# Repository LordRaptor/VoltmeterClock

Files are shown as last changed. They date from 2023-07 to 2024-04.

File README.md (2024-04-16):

# Voltmeter Clock v2.0

## Controls

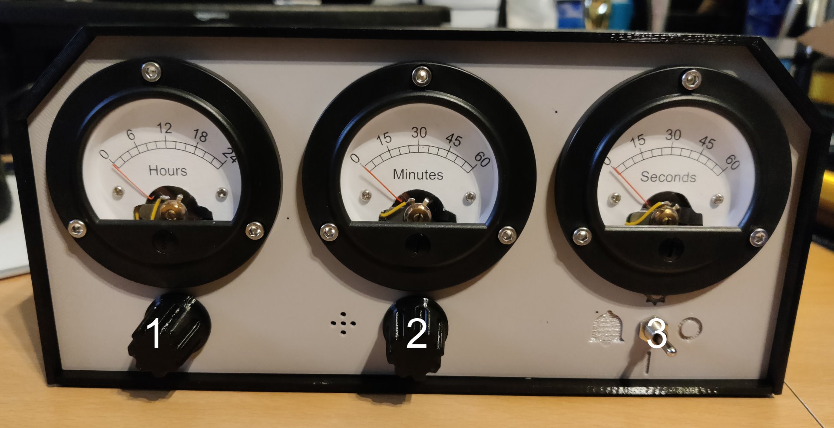
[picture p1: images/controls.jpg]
Controls


* Knob 1: Rotate to change backlight brightness. Press and hold for 1-2s to enter time setting mode
* Knob 2: Click to change time display mode
* Switch 3: Controls alarm

## Startup
When the clock is connected to power, a startup routine will run, slowly pulsing the backlights and moving all indicators to their maximum position and back, before continuing to normal operation. If the timekeeping was lost, the clock will instead switch to time setting mode.

Use this to confirm that all indicators move freely.

## Backlight
There is a yellow LED backlight installed in each display. Use __Knob 1__ to increase or decrease brightness.  Rotate clockwise to increase and counter-clockwise to decrease backlight brightness. This setting persists, even if power is lost

## Time display mode

The clock supports two modes to display time, _digital_ and _analog_. Press __Knob 2__ to switch between these. This setting persists, even if power is lost.

* _Digital display mode_: Indicators will point to the current hour, minute and second and move in discrete steps as time moves on. So the seconds indicator will move once per seconds, the minute indicator once per minute and the hours indicator once per hour.
* _Analog display mode_: Indicators will move smoothly as time progresses.

## Time setting mode
Press and hold __Knob 1__ until the backlight LEDs start blinking (1-2 seconds). The clock will always switch to _digital display mode_ to make setting the time easier. Rotate __Knob 1__ to set the hour, and __Knob 2__ to set the minute. Press __Knob 1__ again (a short click will be enough) to exit time setting mode. Seconds will always be reset to 0 and start counting again when the new time is confirmed.

## Alarm

__Switch 3__ has three positions:

* __Up:__ Set alarm time
* __Middle:__ Alarm disabled
* __Down:__ Alarm armed

To set the alarm, move the __Switch 3__ to the __up__ position. Use __Knob 1__ and __Knob 2__ to set the hour and minute of the alarm time. Note that the minutes can only be set in 5 min intervals.

While setting the alarm time, press __Knob 2__ to change the alarm melody. 6 different melodies are available

1. Star Wars
1. Game of Thrones
1. Harry Potter
1. Pirates of the Caribbean
1. Tetris
1. Mario

To save the alarm time, move __Switch 3__ to the __middle__ or __down__ position.

Alarm time and selected melody is persisted, even if power is lost.

## Calibration Mode
Not used in normal operation.

Pressing __Knob 2__ for 1-2 seconds will enter calibration mode, backlight LEDs  will start pulsing slowly. This mode is used to calibrate the displays,
adjusting the display potentiometers on the circuit board until the indicators points to the end of the dial scale. __Knob 1__ will move the hour dial, __Knob 2__ will move the minutes and seconds dials.

Long pressing __Knob 1__ again for 1-2 seconds will exit this mode and normal operation will resume.

## Backup power
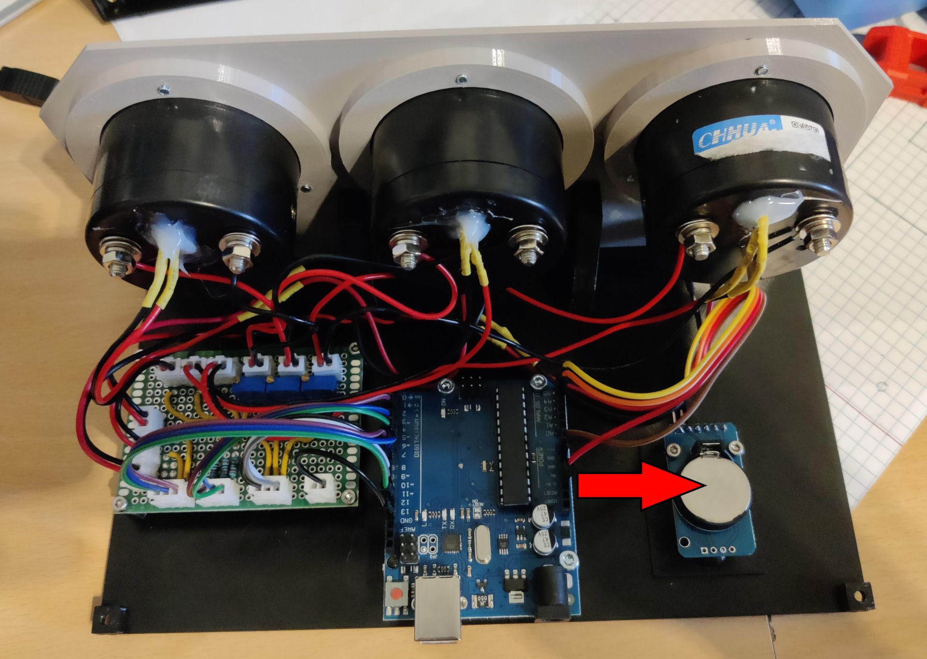
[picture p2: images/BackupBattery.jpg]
Coin cell battery location


The clock includes a slot for a CR2032 3V coin cell battery to ensure time keeping even if main power is lost. To replace the battery, open the clock by removing the four (4) screws at the bottom of the clock and lifting off the outer case. Insert the coin cell battery into the holder located on the small module in the clock (see picture).

## Power Supply
Ideally the clock is powered using a 5.5 X 2.1 jack with a 7-12V power supply, with ~7V being recommended.

Powering the clock via the USB B port (which only provides 5V) will also work, but
the display will not be accurate as the backlight brightness will affect the indicators in this case.

## Serial output
Connecting a USB B cable to the clock, a serial monitor using a baud rate of 115200 will allow you to read the debug output of the clock.

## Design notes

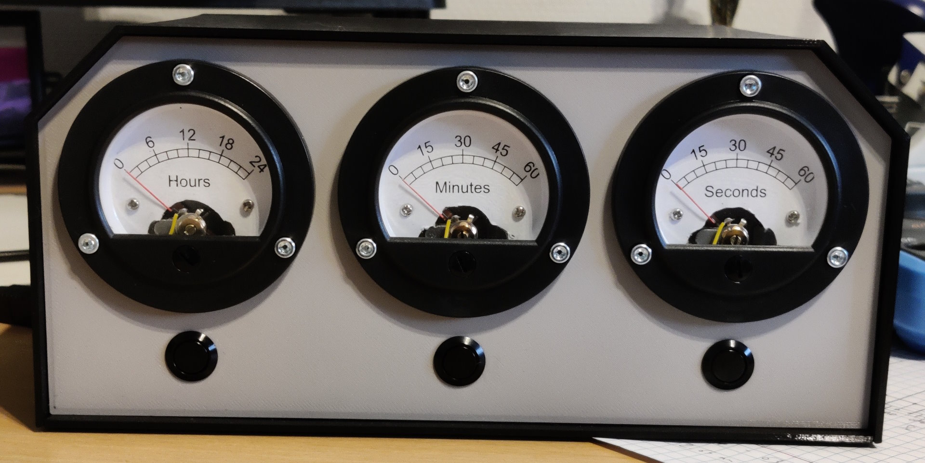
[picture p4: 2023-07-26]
images/Front.jpg

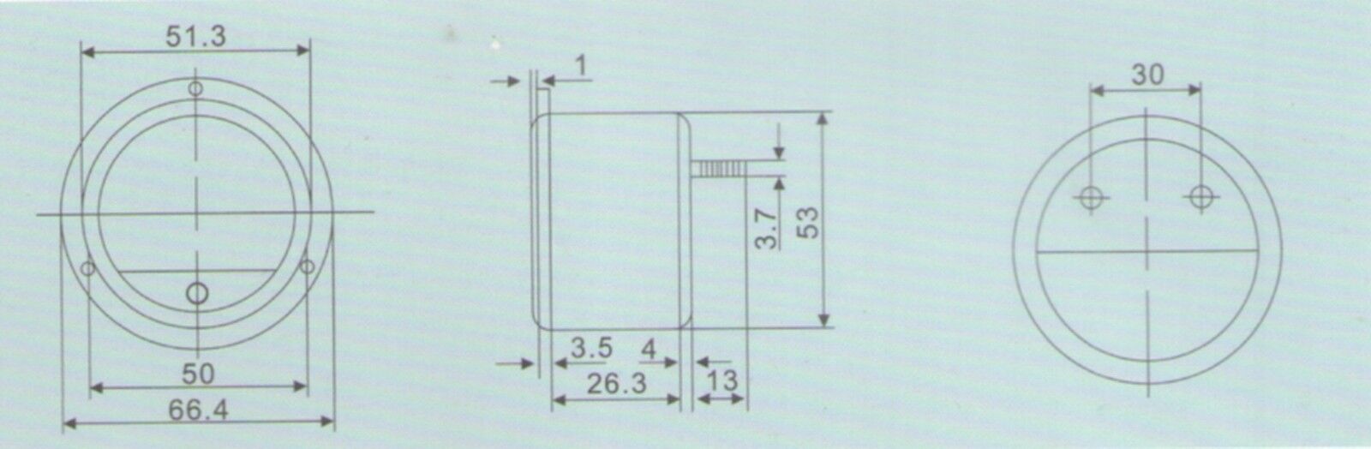
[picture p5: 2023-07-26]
assets/3D Models/DH-52 Dimensions.jpg

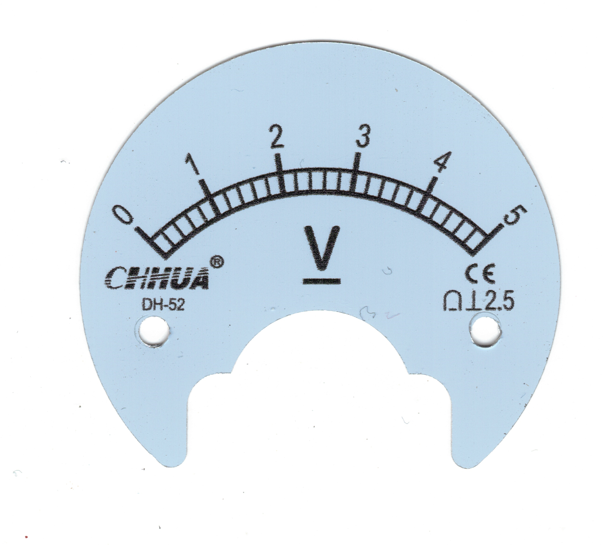
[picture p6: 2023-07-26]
assets/Dials/DH-52 Dial.png

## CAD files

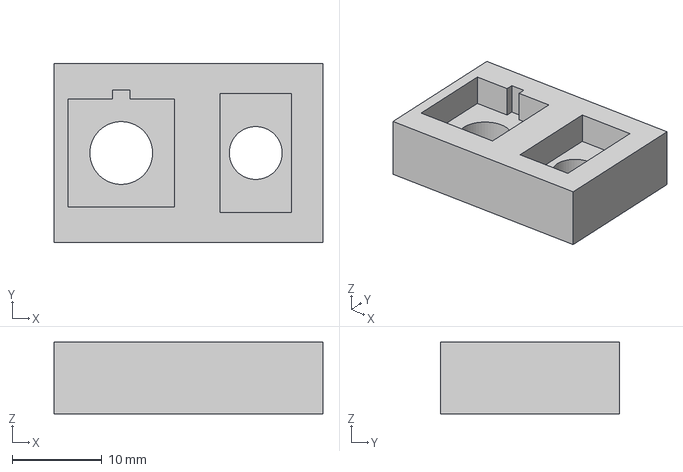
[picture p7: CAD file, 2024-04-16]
assets/3D Models/Encoder and Switch Fitting Test v1.3mf
30.0 x 20.0 x 8.00 mm

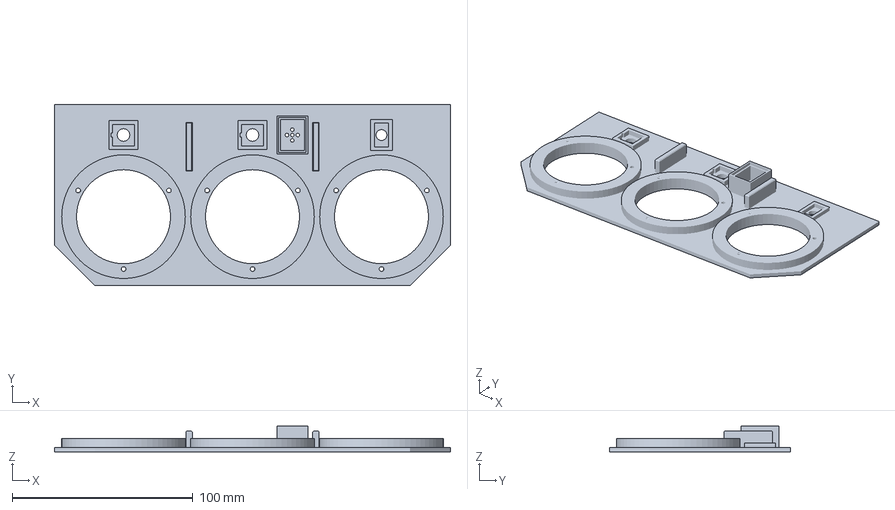
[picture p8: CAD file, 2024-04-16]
assets/3D Models/Version 2/Front 2.0.3mf
219.2 x 100.4 x 14.3 mm

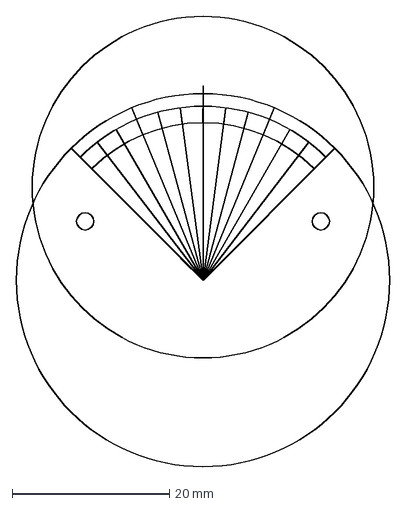
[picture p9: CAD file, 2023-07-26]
assets/Dials/Dial Scale.dxf
47.5 x 57.3 mm

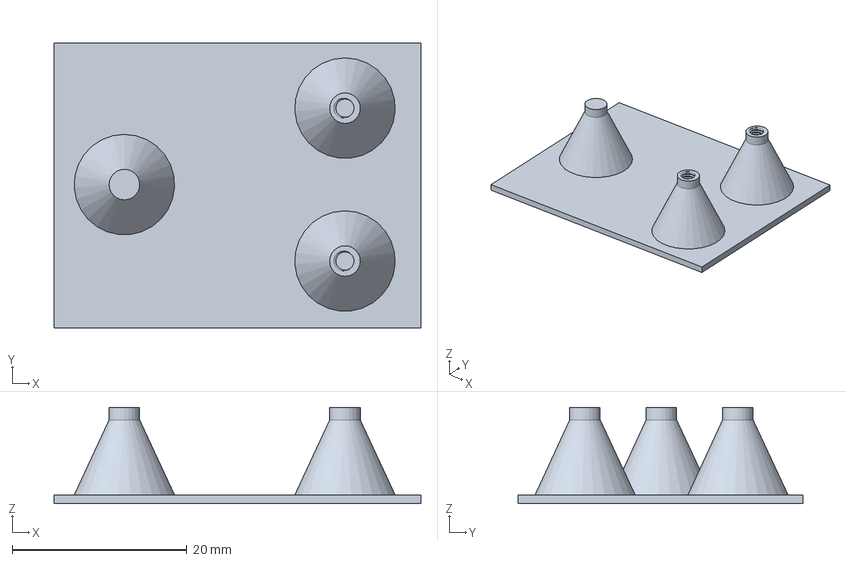
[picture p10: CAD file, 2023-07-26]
assets/3D Models/RTC Holder.3mf
42.0 x 32.7 x 11.0 mm

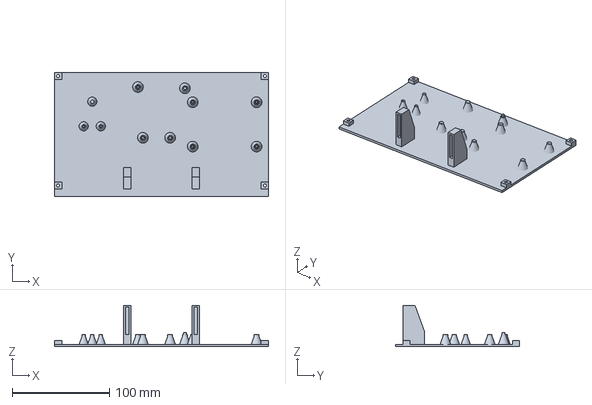
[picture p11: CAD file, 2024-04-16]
assets/3D Models/Version 2/Bottom 2.0.3mf
219.6 x 127.4 x 42.5 mm

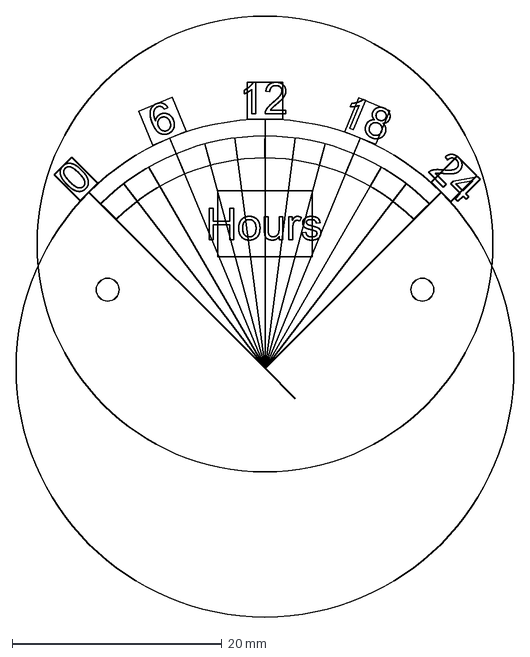
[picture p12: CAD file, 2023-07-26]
assets/Dials/Hours Dial.dxf
47.5 x 57.3 mm

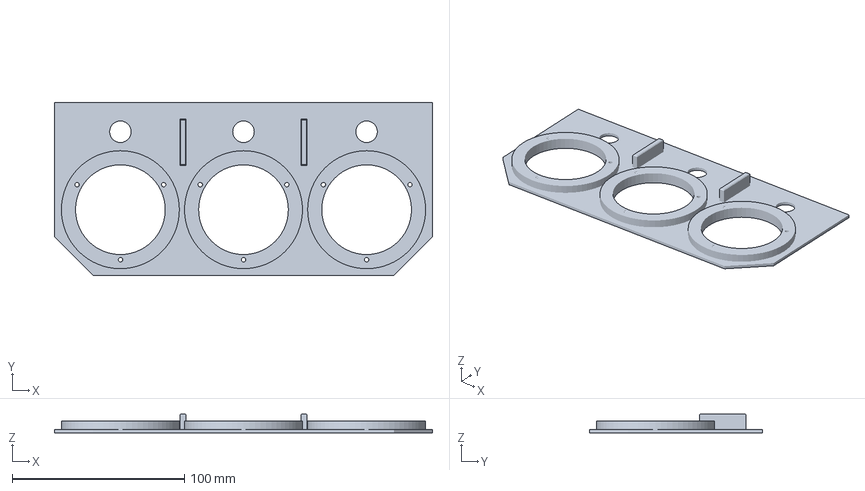
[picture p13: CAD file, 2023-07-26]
assets/3D Models/Frontpanel.3mf
219.2 x 100.4 x 11.0 mm

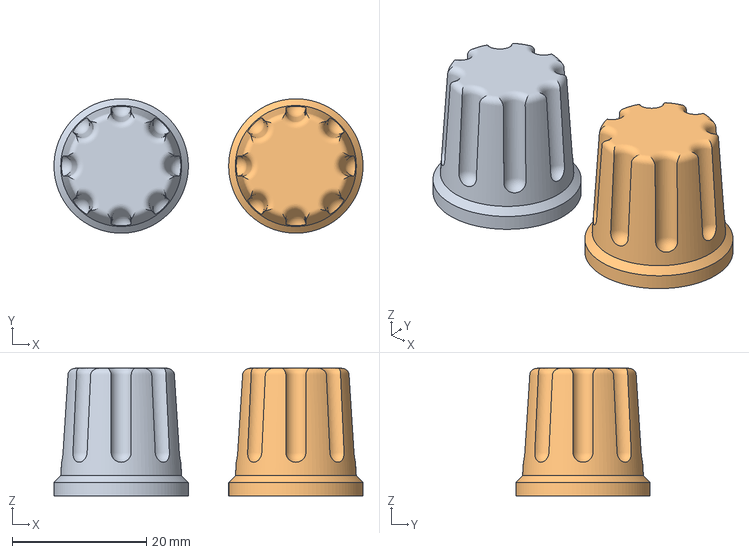
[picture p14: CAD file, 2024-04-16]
assets/3D Models/Version 2/Kob v9.3mf
46.0 x 20.0 x 19.0 mm

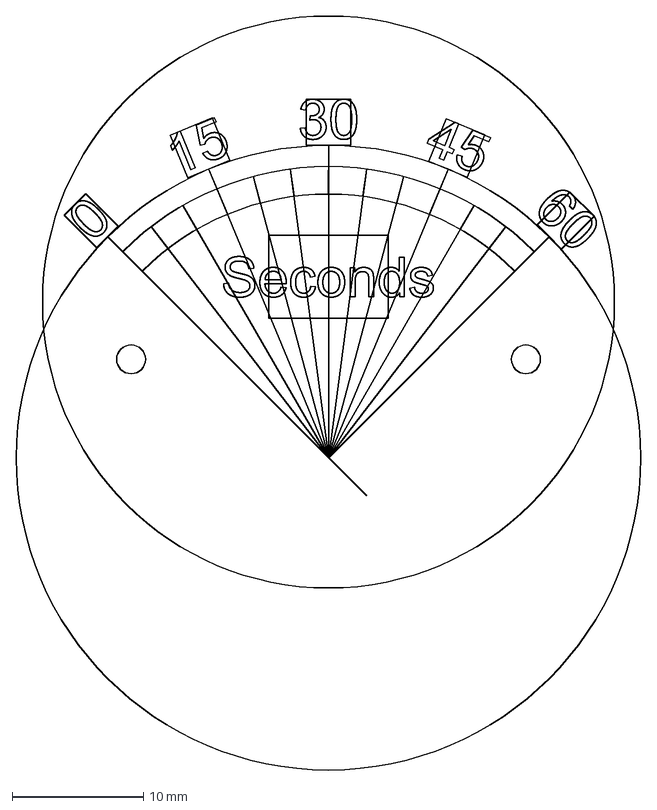
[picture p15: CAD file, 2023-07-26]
assets/Dials/Seconds Dial.dxf
47.5 x 57.3 mm

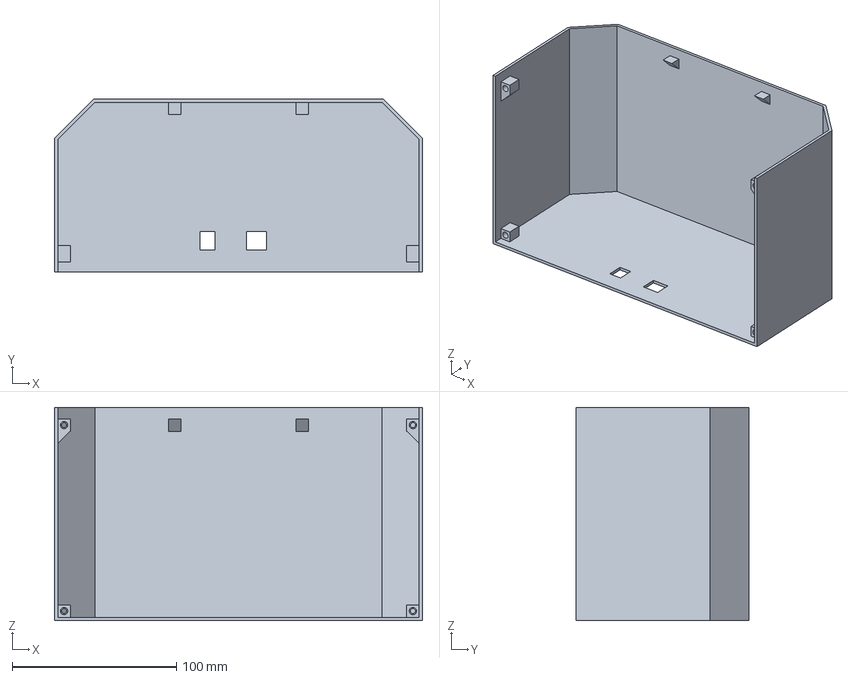
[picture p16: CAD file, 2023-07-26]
assets/3D Models/Case.3mf
224.2 x 105.4 x 130.0 mm

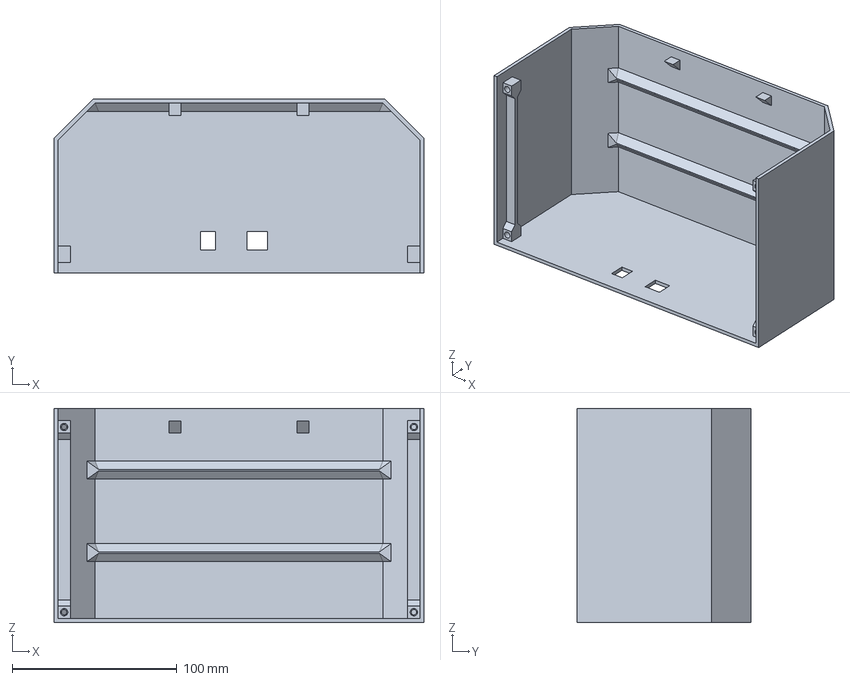
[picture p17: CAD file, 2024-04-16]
assets/3D Models/Version 2/Case 2.0.3mf
224.4 x 105.6 x 130.0 mm

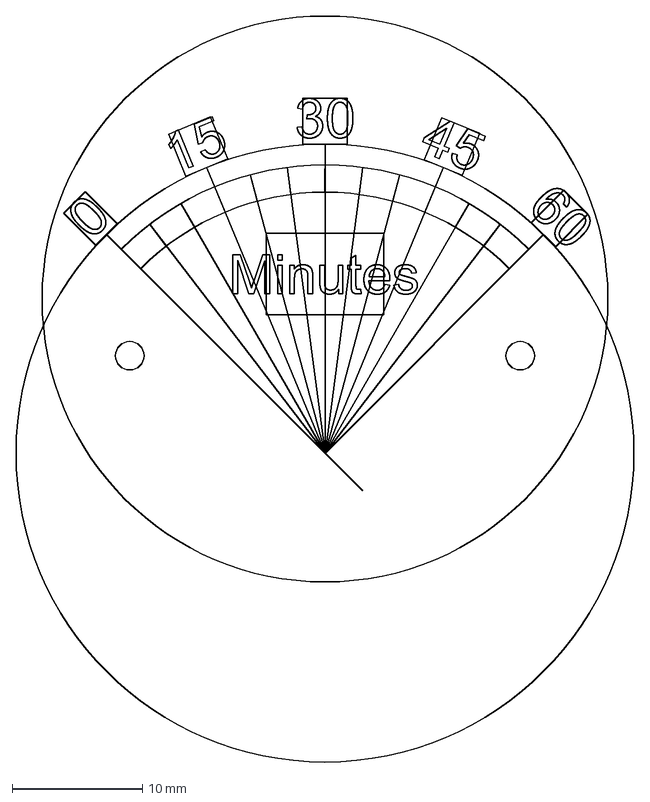
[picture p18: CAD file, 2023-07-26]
assets/Dials/Minutes Dial.dxf
47.5 x 57.3 mm

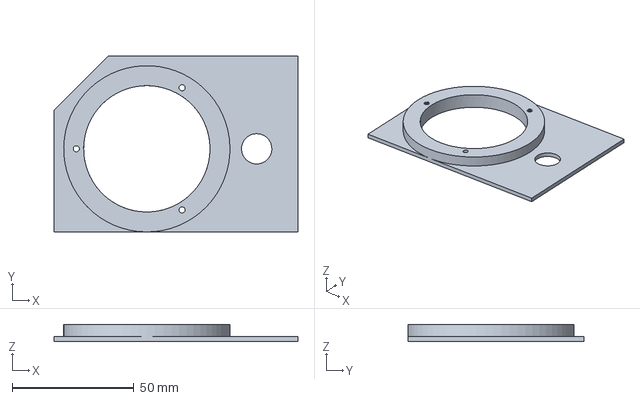
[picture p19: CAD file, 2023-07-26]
assets/3D Models/FrontPanel Fit Test.3mf
100.4 x 72.4 x 7.00 mm

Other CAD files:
assets/3D Models/Bottom Panel.3mf
assets/3D Models/Version 2/Front 2.0 v13.3mf

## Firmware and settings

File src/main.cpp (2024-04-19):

#define VERBOSE_DEBUG

#include <Arduino.h>
#include <voltmeter/VoltmeterManager.h>
#include <led/SmoothLedManager.h>
#include <RTClib.h>
#include <avdweb_Switch.h>
#include <Encoder.h>
#include <alarm/ToneAlarm.h>


// Voltmeters
// Do not use Pins 5 and 6 for Voltmeters
#define HOURS_VOLTMETER_PIN 10
#define MINUTES_VOLTMETER_PIN 9
#define SECONDS_VOLTMETER_PIN 6
#define VOLTMETER_STEPS_PER_SECOND 255

// LEDs
#define LED_PIN 5

// Buzzer
#define BUZZER_PIN 11

// Rotary Encoders
#define HOURS_ENCODER_CLK 2
#define HOURS_ENCODER_DT 3
#define HOURS_ENCODER_SWITCH 14
#define MINUTES_ENCODER_CLK 17
#define MINUTES_ENCODER_DT 16
#define MINUTES_ENCODER_SWITCH 15

// Front switch
#define FRONT_SWITCH_UP 7
#define FRONT_SWITCH_DOWN 8

// Alarm
#define ALARM_LOOP_COUNT 3

// put function declarations here:
void startupRoutine();
void displayTimeLoop();

void writeTimetoSerial(uint8_t hours, uint8_t minutes, uint8_t seconds);

void enterSettings();
void settingStateLoop();
void exitSettings();

void enterCalibration();
void calibrationStateLoop();
void exitCalibration();

void enterAlarmSet();
void alarmSetLoop();
void exitAlarmSet();

void buttonSingleClickedCallback(void *ref);
void buttonLongPressedCallback(void *ref);
void buttonPushedCallback(void *ref);

void readEncoders();

const byte HOUR_SWITCH_ID = 1;
const byte MINUTES_SWITCH_ID = 2;
const byte FRONT_SWITCH_UP_ID = 3;
const byte FRONT_SWITCH_DOWN_ID = 4;

enum ClockState
{
  startup,
  displayTime,
  setting,
  calibration,
  setAlarm
};
ClockState state = startup;

struct TimeData
{
  uint8_t hours = 0;
  uint8_t minutes = 0;
  uint8_t seconds = 0;
};
TimeData rtcTimeHolder = {};

struct DisplayTimeStateData
{
  unsigned long lastRTCPoll = 0;
  unsigned long lastSecondChange = 0;
  unsigned long lastSerialOutput = 0;

  unsigned long rtcUpdateInterval = 50;
  unsigned long serialOutputInterval = 10000;
};
DisplayTimeStateData displayStateData = {};

SmoothLedManager ledManager(LED_PIN);

VoltmeterManager voltmeterManager(
    VoltmeterConfig{
        HOURS_VOLTMETER_PIN,
        MINUTES_VOLTMETER_PIN,
        SECONDS_VOLTMETER_PIN,
        VOLTMETER_STEPS_PER_SECOND});

Switch hourButton = Switch(HOURS_ENCODER_SWITCH, INPUT_PULLUP, LOW, 50, 2000, 250, 10);
Switch minutesButton = Switch(MINUTES_ENCODER_SWITCH, INPUT_PULLUP, LOW, 50, 2000, 250, 10);

Switch alarmSetButton = Switch(FRONT_SWITCH_UP, INPUT_PULLUP, LOW, 50, 1000, 250, 10);

Encoder hourEncoder = Encoder(HOURS_ENCODER_CLK, HOURS_ENCODER_DT);
Encoder minutesEncoder = Encoder(MINUTES_ENCODER_CLK, MINUTES_ENCODER_DT);

struct EncoderData
{
  long encoderPos = 0;
  long newEncoderPos = 0;
  bool encoderUp = false;
  bool encoderDown = false;
};

EncoderData hourEncoderData = {};
EncoderData minutesEncoderData = {};

RTC_DS3231 rtc;

ToneAlarm toneAlarm = ToneAlarm(BUZZER_PIN);

void setup()
{
  pinMode(BUZZER_PIN, OUTPUT);
  noTone(BUZZER_PIN);

  Serial.begin(115200);

  if (!rtc.begin())
  {
    Serial.println(F("Couldn't find RTC"));
    Serial.flush();
    while (true)
      ;
    // TODO: Enter an error state
  }
  Serial.println(F("Found RTC"));

  rtc.disable32K();
  rtc.clearAlarm(1);
  rtc.clearAlarm(2);
  rtc.disableAlarm(2);

  hourButton.setSingleClickCallback(&buttonSingleClickedCallback, (void *)&HOUR_SWITCH_ID);
  minutesButton.setSingleClickCallback(&buttonSingleClickedCallback, (void *)&MINUTES_SWITCH_ID);

  hourButton.setLongPressCallback(&buttonLongPressedCallback, (void *)&HOUR_SWITCH_ID);
  minutesButton.setLongPressCallback(&buttonLongPressedCallback, (void *)&MINUTES_SWITCH_ID);

  alarmSetButton.setPushedCallback(&buttonPushedCallback, (void *)&FRONT_SWITCH_UP_ID);

  pinMode(FRONT_SWITCH_DOWN, INPUT_PULLUP);

  ledManager.begin();

  voltmeterManager.begin();

  toneAlarm.begin();

  state = startup;
}

void loop()
{
  readEncoders();
  hourButton.poll();
  minutesButton.poll();
  alarmSetButton.poll();

  switch (state)
  {
  case startup:
    startupRoutine();
    break;
  case displayTime:
    displayTimeLoop();
    break;
  case setting:
    settingStateLoop();
    break;
  case calibration:
    calibrationStateLoop();
    break;
  case setAlarm:
    alarmSetLoop();
    break;
  default:
    break;
  }

  voltmeterManager.updateVoltmeters();
  ledManager.update();
}

// put function definitions here:
void startupRoutine()
{
  voltmeterManager.setStepsPerSecond(64);
  voltmeterManager.setDisplayMode(digital);
  voltmeterManager.updateTime(24, 60, 60, 0);
  ledManager.setMode(pulsing);

  while (!voltmeterManager.updateVoltmeters())
  {
    ledManager.update();
  }

  voltmeterManager.updateTime(0, 0, 0, 0);
  while (!voltmeterManager.updateVoltmeters())
  {
    ledManager.update();
  }

  voltmeterManager.resetDisplayMode();
  voltmeterManager.setStepsPerSecond(VOLTMETER_STEPS_PER_SECOND);
  ledManager.setMode(saved_level);
  ledManager.restoreLedBrightness();
  ledManager.update();

  Serial.println(F("Startup completed"));
  if (rtc.lostPower())
  {
    Serial.println(F("RTC lost power"));
    enterSettings();
  }
  else
  {
    Serial.println(F("Switching to time display mode"));
    state = displayTime;
  }
}

void displayTimeLoop()
{

  if (hourEncoderData.encoderUp || hourEncoderData.encoderDown) {
    if (ledManager.changeLedBrightness(hourEncoderData.encoderUp ? 5 : -5))
    {
      ledManager.saveLedBrightness();
    }
    
  }

  unsigned long localNow = millis();
  if (displayStateData.rtcUpdateInterval <= (localNow - displayStateData.lastRTCPoll))
  {
    DateTime rtcNow = rtc.now();
    rtcTimeHolder.hours = rtcNow.hour();
    rtcTimeHolder.minutes = rtcNow.minute();
    if (rtcNow.second() != rtcTimeHolder.seconds)
    {
      rtcTimeHolder.seconds = rtcNow.second();
      displayStateData.lastSecondChange = localNow;
    }

    voltmeterManager.updateTime(rtcTimeHolder.hours, rtcTimeHolder.minutes, rtcTimeHolder.seconds, localNow - displayStateData.lastSecondChange);
    displayStateData.lastRTCPoll = localNow;
  }
  if (displayStateData.serialOutputInterval <= (localNow - displayStateData.lastSerialOutput))
  {
    Serial.print(rtc.getTemperature());
    Serial.print(F("°C "));
    writeTimetoSerial(rtcTimeHolder.hours, rtcTimeHolder.minutes, rtcTimeHolder.seconds);
    displayStateData.lastSerialOutput = localNow;
  }

  if (!digitalRead(FRONT_SWITCH_DOWN))
  {
    if (rtc.alarmFired(1)) {
      Serial.println("Alarm fired");
      rtc.clearAlarm(1);
      toneAlarm.start(ALARM_LOOP_COUNT);
    }
    toneAlarm.play();
  } else {
    toneAlarm.stop();

    // Clear the alarm flag if it fired
    if (rtc.alarmFired(1)) {
      rtc.clearAlarm(1);
    }
  }
}

void enterSettings()
{
  Serial.println(F("Entering settings state"));
  state = setting;

  if (rtc.lostPower())
  {
    rtcTimeHolder.hours = 0;
    rtcTimeHolder.minutes = 0;
    rtcTimeHolder.seconds = 0;
  }
  else
  {
    DateTime dt = rtc.now();
    rtcTimeHolder.hours = dt.hour();
    rtcTimeHolder.minutes = dt.minute();
    rtcTimeHolder.seconds = 0;
  }

  writeTimetoSerial(rtcTimeHolder.hours, rtcTimeHolder.minutes, rtcTimeHolder.seconds);

  voltmeterManager.setDisplayMode(digital);
  voltmeterManager.updateTime(rtcTimeHolder.hours, rtcTimeHolder.minutes, rtcTimeHolder.seconds, 0);

  ledManager.setMode(blinking);
}

void settingStateLoop()
{
  if (hourButton.pushed())
  {
    exitSettings();
  }
  else if (hourEncoderData.encoderUp || hourEncoderData.encoderDown)
  {
    rtcTimeHolder.hours = constrain(rtcTimeHolder.hours + (hourEncoderData.encoderUp ? 1 : -1), 0, 23);
    writeTimetoSerial(rtcTimeHolder.hours, rtcTimeHolder.minutes, rtcTimeHolder.seconds);
    voltmeterManager.updateTime(rtcTimeHolder.hours, rtcTimeHolder.minutes, rtcTimeHolder.seconds, 0);
  }
  else if (minutesEncoderData.encoderUp || minutesEncoderData.encoderDown)
  {
    rtcTimeHolder.minutes =  constrain(rtcTimeHolder.minutes + (minutesEncoderData.encoderUp ? 1 : -1), 0, 59);
    writeTimetoSerial(rtcTimeHolder.hours, rtcTimeHolder.minutes, rtcTimeHolder.seconds);
    voltmeterManager.updateTime(rtcTimeHolder.hours, rtcTimeHolder.minutes, rtcTimeHolder.seconds, 0);
  }
}

void exitSettings()
{

  state = displayTime;
  rtc.adjust(DateTime(2023, 1, 1, rtcTimeHolder.hours, rtcTimeHolder.minutes, rtcTimeHolder.seconds));

  // Force an update
  displayStateData.lastRTCPoll = 0;
  displayStateData.lastSerialOutput = 0;

  voltmeterManager.resetDisplayMode();

  ledManager.setMode(saved_level);

  Serial.println(F("Exiting settings state"));
}

void enterCalibration()
{
  Serial.println(F("Entering calibration state"));
  voltmeterManager.setDisplayMode(digital);
  rtcTimeHolder.hours = 24;
  rtcTimeHolder.minutes = 60;
  rtcTimeHolder.seconds = 60;

  voltmeterManager.updateTime(rtcTimeHolder.hours, rtcTimeHolder.minutes, rtcTimeHolder.seconds, 0);
  voltmeterManager.printTargets();
  writeTimetoSerial(rtcTimeHolder.hours, rtcTimeHolder.minutes, rtcTimeHolder.seconds);
  ledManager.setMode(on);

  state = calibration;
}

void calibrationStateLoop()
{
  // Used to calibrate the voltmeters
  if (hourEncoderData.encoderUp || hourEncoderData.encoderDown)
  {
    rtcTimeHolder.hours = constrain(rtcTimeHolder.hours + (hourEncoderData.encoderUp ? 1 : -1), 0, 24);
    voltmeterManager.updateTime(rtcTimeHolder.hours, rtcTimeHolder.minutes, rtcTimeHolder.seconds, 0);
    voltmeterManager.printTargets();
    writeTimetoSerial(rtcTimeHolder.hours, rtcTimeHolder.minutes, rtcTimeHolder.seconds);
  }
  else if (minutesEncoderData.encoderUp || minutesEncoderData.encoderDown)
  {
    rtcTimeHolder.minutes = constrain(rtcTimeHolder.minutes + (minutesEncoderData.encoderUp ? 5 : -5), 0, 60);
        rtcTimeHolder.seconds = rtcTimeHolder.minutes;
    voltmeterManager.updateTime(rtcTimeHolder.hours, rtcTimeHolder.minutes, rtcTimeHolder.seconds, 0);
    voltmeterManager.printTargets();
    writeTimetoSerial(rtcTimeHolder.hours, rtcTimeHolder.minutes, rtcTimeHolder.seconds);
  }
}

void exitCalibration()
{
  voltmeterManager.resetDisplayMode();
  ledManager.setMode(saved_level);

  // Force an update
  displayStateData.lastRTCPoll = 0;
  displayStateData.lastSerialOutput = 0;

  state = displayTime;
  Serial.println(F("Exiting calibration state"));
}

void enterAlarmSet() {
  Serial.println(F("Entering alarm set state"));
  voltmeterManager.setDisplayMode(digital);
  state = setAlarm;

  DateTime alarm = rtc.getAlarm1();
  rtcTimeHolder.hours = alarm.hour();
  rtcTimeHolder.minutes = alarm.minute();
  rtcTimeHolder.seconds = 0;

  voltmeterManager.updateTime(rtcTimeHolder.hours, rtcTimeHolder.minutes, rtcTimeHolder.seconds, 0);
  writeTimetoSerial(rtcTimeHolder.hours, rtcTimeHolder.minutes, rtcTimeHolder.seconds);
  ledManager.setMode(pulsing);
}

void alarmSetLoop() {
  if (alarmSetButton.released())
  {
    exitAlarmSet();
  }
  else if (hourEncoderData.encoderUp || hourEncoderData.encoderDown)
  {
    rtcTimeHolder.hours = constrain(rtcTimeHolder.hours + (hourEncoderData.encoderUp ? 1 : -1), 0, 23);
    writeTimetoSerial(rtcTimeHolder.hours, rtcTimeHolder.minutes, rtcTimeHolder.seconds);
    voltmeterManager.updateTime(rtcTimeHolder.hours, rtcTimeHolder.minutes, rtcTimeHolder.seconds, 0);
  }
  else if (minutesEncoderData.encoderUp || minutesEncoderData.encoderDown)
  {
    rtcTimeHolder.minutes =  constrain(rtcTimeHolder.minutes + (minutesEncoderData.encoderUp ? 5 : -5), 0, 55);
    writeTimetoSerial(rtcTimeHolder.hours, rtcTimeHolder.minutes, rtcTimeHolder.seconds);
    voltmeterManager.updateTime(rtcTimeHolder.hours, rtcTimeHolder.minutes, rtcTimeHolder.seconds, 0);
  }

  toneAlarm.play();
}

void exitAlarmSet() {

  
  DateTime newAlarmTime = DateTime(0, 0, 0, rtcTimeHolder.hours, rtcTimeHolder.minutes, 0);
  rtc.setAlarm1(newAlarmTime, DS3231_A1_Hour);

  // Force an update
  displayStateData.lastRTCPoll = 0;
  displayStateData.lastSerialOutput = 0;

  voltmeterManager.resetDisplayMode();

  ledManager.setMode(saved_level);

  toneAlarm.stop();

  state = displayTime;
  Serial.print(F("Exiting alarm set state, alarm set to "));
  writeTimetoSerial(newAlarmTime.hour(), newAlarmTime.minute(), 0);
}

void writeTimetoSerial(uint8_t hours, uint8_t minutes, uint8_t seconds)
{
  if (hours < 10)
  {
    Serial.print("0");
  }
  Serial.print(hours);
  Serial.print(":");
  if (minutes < 10)
  {
    Serial.print("0");
  }
  Serial.print(minutes);
  Serial.print(":");
  if (seconds < 10)
  {
    Serial.print("0");
  }
  Serial.println(seconds);
}

void buttonSingleClickedCallback(void *ref)
{
  byte b = *((byte *)ref);

  Serial.print(F("Button clicked: "));
  Serial.println(b);

  if (b == MINUTES_SWITCH_ID)
  {
    Serial.print(F("Clock state: "));
    Serial.println(state);
    if (state == displayTime)
    {
      // Change voltmeter display mode
      voltmeterManager.changeDisplayMode();
      voltmeterManager.saveCurrentDisplayMode();
      displayStateData.lastRTCPoll = 0; // Force update
    }
     else if (state == setAlarm)
    {
      toneAlarm.changeMelody();
      toneAlarm.start(1);
    }

  }
}

void buttonLongPressedCallback(void *ref)
{
  byte b = *((byte *)ref);

  Serial.print(F("Button long pressed: "));
  Serial.println(b);

  if (b == HOUR_SWITCH_ID && state == displayTime)
  {
    enterSettings();
  }
  else if (b == MINUTES_SWITCH_ID)
  {
    if (state == displayTime)
    {
      enterCalibration();
    }
    else if (state == calibration)
    {
      exitCalibration();
    }
  }
}

void buttonPushedCallback(void *ref) {
    byte b = *((byte *)ref);
    if (b == FRONT_SWITCH_UP_ID && state == displayTime) {
      enterAlarmSet();
    }
}

void readEncoders() {
  hourEncoderData.newEncoderPos = hourEncoder.read();
  minutesEncoderData.newEncoderPos = minutesEncoder.read();

  if (abs(hourEncoderData.encoderPos - hourEncoderData.newEncoderPos) >= 4) {
    hourEncoderData.encoderDown = hourEncoderData.encoderPos < hourEncoderData.newEncoderPos;
    hourEncoderData.encoderUp = hourEncoderData.encoderPos > hourEncoderData.newEncoderPos;
    hourEncoderData.encoderPos = hourEncoderData.newEncoderPos;
  }
  else
  {
      hourEncoderData.encoderDown = false;
      hourEncoderData.encoderUp = false;
  }
  

  if (abs(minutesEncoderData.encoderPos - minutesEncoderData.newEncoderPos) >= 4) {
    minutesEncoderData.encoderDown = minutesEncoderData.encoderPos < minutesEncoderData.newEncoderPos;
    minutesEncoderData.encoderUp = minutesEncoderData.encoderPos > minutesEncoderData.newEncoderPos;
    minutesEncoderData.encoderPos = minutesEncoderData.newEncoderPos;
  }
  else
  {
      minutesEncoderData.encoderDown = false;
      minutesEncoderData.encoderUp = false;
  }
  
}

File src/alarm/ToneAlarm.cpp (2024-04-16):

#include "ToneAlarm.h"
#include "Arduino.h"
#include "EEPROM.h"
#include "eewl.h"

// EEPROM circular buffer configuration
#define BUFFER_START 0x40 // buffer start address
#define BUFFER_LEN 10     // number of data blocks
#define MELODY_COUNT 6

byte melodyIndex;

EEWL storedMelody(melodyIndex, BUFFER_LEN, BUFFER_START);

const PROGMEM unsigned int starwarsNotes[] = {
  NOTE_AS4, NOTE_AS4, NOTE_AS4,
  NOTE_F5, NOTE_C6,
  NOTE_AS5, NOTE_A5, NOTE_G5, NOTE_F6, NOTE_C6,
  NOTE_AS5, NOTE_A5, NOTE_G5, NOTE_F6, NOTE_C6,
  NOTE_AS5, NOTE_A5, NOTE_AS5, NOTE_G5, NOTE_C5, NOTE_C5, NOTE_C5,
  NOTE_F5, NOTE_C6,
  NOTE_AS5, NOTE_A5, NOTE_G5, NOTE_F6, NOTE_C6,

  NOTE_AS5, NOTE_A5, NOTE_G5, NOTE_F6, NOTE_C6,
  NOTE_AS5, NOTE_A5, NOTE_AS5, NOTE_G5, NOTE_C5, NOTE_C5,
  NOTE_D5, NOTE_D5, NOTE_AS5, NOTE_A5, NOTE_G5, NOTE_F5,
  NOTE_F5, NOTE_G5, NOTE_A5, NOTE_G5, NOTE_D5, NOTE_E5, NOTE_C5, NOTE_C5,
  NOTE_D5, NOTE_D5, NOTE_AS5, NOTE_A5, NOTE_G5, NOTE_F5,

  NOTE_C6, NOTE_G5, NOTE_G5, REST, NOTE_C5,
  NOTE_D5, NOTE_D5, NOTE_AS5, NOTE_A5, NOTE_G5, NOTE_F5,
  NOTE_F5, NOTE_G5, NOTE_A5, NOTE_G5, NOTE_D5, NOTE_E5, NOTE_C6, NOTE_C6,
  NOTE_F6, NOTE_DS6, NOTE_CS6, NOTE_C6, NOTE_AS5, NOTE_GS5, NOTE_G5, NOTE_F5,
  NOTE_C6

};

const PROGMEM byte starwarsDurations[] = 
{
  8, 8, 8,
  2, 2,
  8, 8, 8, 2, 4,
  8, 8, 8, 2, 4,
  8, 8, 8, 2, 8, 8, 8,
  2, 2,
  8, 8, 8, 2, 4,

  8, 8, 8, 2, 4,
  8, 8, 8, 2, 8, 16,
  4, 8, 8, 8, 8, 8,
  8, 8, 8, 4, 8, 4, 8, 16,
  4, 8, 8, 8, 8, 8,

  8, 16, 2, 8, 8,
  4, 8, 8, 8, 8, 8,
  8, 8, 8, 4, 8, 4, 8, 16,
  4, 8, 4, 8, 4, 8, 4, 8,
  1
};

const PROGMEM unsigned int gameOfThronesNotes[] = {
  NOTE_G4, NOTE_C4, NOTE_DS4, NOTE_F4, NOTE_G4, NOTE_C4, NOTE_DS4, NOTE_F4,
  NOTE_G4, NOTE_C4, NOTE_DS4, NOTE_F4, NOTE_G4, NOTE_C4, NOTE_DS4, NOTE_F4,
  NOTE_G4, NOTE_C4, NOTE_E4, NOTE_F4, NOTE_G4, NOTE_C4, NOTE_E4, NOTE_F4,
  NOTE_G4, NOTE_C4, NOTE_E4, NOTE_F4, NOTE_G4, NOTE_C4, NOTE_E4, NOTE_F4,
  NOTE_G4, NOTE_C4,
  
  NOTE_DS4, NOTE_F4, NOTE_G4, NOTE_C4, NOTE_DS4, NOTE_F4,
  NOTE_D4,
  NOTE_F4, NOTE_AS3,
  NOTE_DS4, NOTE_D4, NOTE_F4, NOTE_AS3,
  NOTE_DS4, NOTE_D4, NOTE_C4,
  
  NOTE_G4, NOTE_C4,
  
  NOTE_DS4, NOTE_F4, NOTE_G4, NOTE_C4, NOTE_DS4, NOTE_F4,
  NOTE_D4,
  NOTE_F4, NOTE_AS3,
  NOTE_DS4, NOTE_D4, NOTE_F4, NOTE_AS3,
  NOTE_DS4, NOTE_D4, NOTE_C4,
  NOTE_G4, NOTE_C4,
  NOTE_DS4, NOTE_F4, NOTE_G4,  NOTE_C4, NOTE_DS4, NOTE_F4,
  
  NOTE_D4,
  NOTE_F4, NOTE_AS3,
  NOTE_D4, NOTE_DS4, NOTE_D4, NOTE_AS3,
  NOTE_C4,
  NOTE_C5,
  NOTE_AS4,
  NOTE_C4,
  NOTE_G4,
  NOTE_DS4,
  NOTE_DS4, NOTE_F4,
  NOTE_G4,
  
  NOTE_C5,
  NOTE_AS4,
  NOTE_C4,
  NOTE_G4,
  NOTE_DS4,
  NOTE_DS4, NOTE_D4,
  NOTE_C5, NOTE_G4, NOTE_GS4, NOTE_AS4, NOTE_C5, NOTE_G4, NOTE_GS4, NOTE_AS4,
  NOTE_C5, NOTE_G4, NOTE_GS4, NOTE_AS4, NOTE_C5, NOTE_G4, NOTE_GS4, NOTE_AS4,
  
  REST, NOTE_GS5, NOTE_AS5, NOTE_C6, NOTE_G5, NOTE_GS5, NOTE_AS5,
  NOTE_C6, NOTE_G5, NOTE_GS5, NOTE_AS5, NOTE_C6, NOTE_G5, NOTE_GS5, NOTE_AS5
};

const PROGMEM byte gameOfThronesDurations[] = {
  8, 8, 16, 16, 8, 8, 16, 16,
  8, 8, 16, 16, 8, 8, 16, 16,
  8, 8, 16, 16, 8, 8, 16, 16,
  8, 8, 16, 16, 8, 8, 16, 16,
  4, 4,
  
  16, 16, 4, 4, 16, 16,
  1,
  4, 4,
  16, 16, 4, 4,
  16, 16, 1,
  
  4, 4,
  
  16, 16, 4, 4, 16, 16,
  1,
  4, 4,
  16, 16, 4, 4,
  16, 16, 1,
  4, 4,
  16, 16, 4, 4, 16, 16,
  
  2,
  4, 4,
  8, 8, 8, 8,
  1,
  2,
  2,
  2,
  2,
  2,
  4, 4,
  1,
  
  2,
  2,
  2,
  2,
  2,
  4, 4,
  8, 8, 16, 16, 8, 8, 16, 16,
  8, 8, 16, 16, 8, 8, 16, 16,
  
  4, 16, 16, 8, 8, 16, 16,
  8, 16, 16, 16, 8, 8, 16, 16
};

const PROGMEM unsigned int harryPotterNotes[] = {
  REST, NOTE_D4,
  NOTE_G4, NOTE_AS4, NOTE_A4,
  NOTE_G4, NOTE_D5,
  NOTE_C5, 
  NOTE_A4,
  NOTE_G4, NOTE_AS4, NOTE_A4,
  NOTE_F4, NOTE_GS4,
  NOTE_D4, 
  NOTE_D4,
  
  NOTE_G4, NOTE_AS4, NOTE_A4,
  NOTE_G4, NOTE_D5,
  NOTE_F5, NOTE_E5,
  NOTE_DS5, NOTE_B4,
  NOTE_DS5, NOTE_D5, NOTE_CS5,
  NOTE_CS4, NOTE_B4,
  NOTE_G4,
  NOTE_AS4,
   
  NOTE_D5, NOTE_AS4,
  NOTE_D5, NOTE_AS4,
  NOTE_DS5, NOTE_D5,
  NOTE_CS5, NOTE_A4,
  NOTE_AS4, NOTE_D5, NOTE_CS5,
  NOTE_CS4, NOTE_D4,
  NOTE_D5, 
  REST, NOTE_AS4,  
  
  NOTE_D5, NOTE_AS4,
  NOTE_D5, NOTE_AS4,
  NOTE_F5, NOTE_E5,
  NOTE_DS5, NOTE_B4,
  NOTE_DS5, NOTE_D5, NOTE_CS5,
  NOTE_CS4, NOTE_AS4,
  NOTE_G4
};

const PROGMEM byte harryPotterDurations[] = {
  2, 4,
  4, 8, 4,
  2, 4,
  2, 
  2,
  4, 8, 4,
  2, 4,
  1, 
  4,
  
  4, 8, 4,
  2, 4,
  2, 4,
  2, 4,
  4, 8, 4,
  2, 4,
  1,
  4,
   
  2, 4,
  2, 4,
  2, 4,
  2, 4,
  4, 8, 4,
  2, 4,
  1, 
  4, 4,  
  
  2, 4,
  2, 4,
  2, 4,
  2, 4,
  4, 8, 4,
  2, 4,
  1
};

const PROGMEM unsigned int piratesNotes[] = {
  NOTE_E4, NOTE_G4, NOTE_A4, NOTE_A4, REST,
  NOTE_A4, NOTE_B4, NOTE_C5, NOTE_C5, REST,
  NOTE_C5, NOTE_D5, NOTE_B4, NOTE_B4, REST,
  NOTE_A4, NOTE_G4, NOTE_A4, REST,
  
  NOTE_E4, NOTE_G4, NOTE_A4, NOTE_A4, REST,
  NOTE_A4, NOTE_B4, NOTE_C5, NOTE_C5, REST,
  NOTE_C5, NOTE_D5, NOTE_B4, NOTE_B4, REST,
  NOTE_A4, NOTE_G4, NOTE_A4, REST,
  
  NOTE_E4, NOTE_G4, NOTE_A4, NOTE_A4, REST,
  NOTE_A4, NOTE_C5, NOTE_D5, NOTE_D5, REST,
  NOTE_D5, NOTE_E5, NOTE_F5, NOTE_F5, REST,
  NOTE_E5, NOTE_D5, NOTE_E5, NOTE_A4, REST,
  
  NOTE_A4, NOTE_B4, NOTE_C5, NOTE_C5, REST,
  NOTE_D5, NOTE_E5, NOTE_A4, REST,
  NOTE_A4, NOTE_C5, NOTE_B4, NOTE_B4, REST,
  NOTE_C5, NOTE_A4, NOTE_B4, REST,
  
  NOTE_A4, NOTE_A4,
  //Repeat of first part
  NOTE_A4, NOTE_B4, NOTE_C5, NOTE_C5, REST,
  NOTE_C5, NOTE_D5, NOTE_B4, NOTE_B4, REST,
  NOTE_A4, NOTE_G4, NOTE_A4, REST,
  
  NOTE_E4, NOTE_G4, NOTE_A4, NOTE_A4, REST,
  NOTE_A4, NOTE_B4, NOTE_C5, NOTE_C5, REST,
  NOTE_C5, NOTE_D5, NOTE_B4, NOTE_B4, REST,
  NOTE_A4, NOTE_G4, NOTE_A4, REST,
  
  NOTE_E4, NOTE_G4, NOTE_A4, NOTE_A4, REST,
  NOTE_A4, NOTE_C5, NOTE_D5, NOTE_D5, REST,
  NOTE_D5, NOTE_E5, NOTE_F5, NOTE_F5, REST,
  NOTE_E5, NOTE_D5, NOTE_E5, NOTE_A4, REST,
  
  NOTE_A4, NOTE_B4, NOTE_C5, NOTE_C5, REST,
  NOTE_D5, NOTE_E5, NOTE_A4, REST,
  NOTE_A4, NOTE_C5, NOTE_B4, NOTE_B4, REST,
  NOTE_C5, NOTE_A4, NOTE_B4, REST,
  //End of Repeat
  
  NOTE_E5, REST, REST, NOTE_F5, REST, REST,
  NOTE_E5, NOTE_E5, REST, NOTE_G5, REST, NOTE_E5, NOTE_D5, REST, REST,
  NOTE_D5, REST, REST, NOTE_C5, REST, REST,
  NOTE_B4, NOTE_C5, REST, NOTE_B4, REST, NOTE_A4,
  
  NOTE_E5, REST, REST, NOTE_F5, REST, REST,
  NOTE_E5, NOTE_E5, REST, NOTE_G5, REST, NOTE_E5, NOTE_D5, REST, REST,
  NOTE_D5, REST, REST, NOTE_C5, REST, REST,
  NOTE_B4, NOTE_C5, REST, NOTE_B4, REST, NOTE_A4
};
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

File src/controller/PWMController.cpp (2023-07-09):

#include "PWMController.h"
#include "Arduino.h"

PWMController::PWMController()
{
    this->setSpeed(DEFAULT_SPEED);
};

bool PWMController::addPin(byte pin)
{
    if (enabledPins < MAX_PWN_PINS)
    {
        pwmPins[enabledPins] = pin;
        enabledPins++;
        return true;
    }
    return false;
};

void PWMController::begin()
{
    currentValue = 0;
    targetValue = 0;
    writeOutput();
};

void PWMController::setSpeed(int unitsPerSecond)
{
    this->unitsPerMs = abs(unitsPerSecond) / 1000.f;
};

void PWMController::setTarget(byte target)
{
    if (this->targetValue != target)
    {
        this->targetValue = target;
        this->lastUpdate = millis(); // To avoid jumps when setting a new target
    }
};

byte PWMController::getTarget()
{
    return targetValue;
}

byte PWMController::getCurrent()
{
    return currentValue;
}

bool PWMController::reachedTarget()
{
    return currentValue == targetValue;
};

bool PWMController::moveToTarget()
{
    time_ms now = millis();
    if (currentValue == targetValue)
    {
        return true;
    }

    time_ms timeSinceLastUpdate = now - this->lastUpdate;

    if (timeSinceLastUpdate > 0)
    {
        int changeInValue = round(unitsPerMs * timeSinceLastUpdate);

        // Serial.print("Time since last update: ");
        // Serial.print(timeSinceLastUpdate);
        // Serial.print(", change in value: ");
        // Serial.print(changeInValue);
        // Serial.print(", current speed: ");
        // Serial.print(unitsPerMs);
        // Serial.print(", target: ");
        // Serial.print(targetValue);

        if (changeInValue > 0)
        {
            if (currentValue < targetValue)
            {
                currentValue = min(currentValue + changeInValue, targetValue);
            }
            else
            {
                currentValue = max(currentValue - changeInValue, targetValue);
            }
            // Serial.print(", updated value: ");
            // Serial.print(currentValue);
            writeOutput();

            this->lastUpdate = now;
            return currentValue == targetValue;
        }
        // Serial.println("");
    }
    return false;
};

void PWMController::jumpToTarget()
{
    if (currentValue != targetValue)
    {
        currentValue = targetValue;
        writeOutput();
    }
};

void PWMController::writeOutput()
{
    for (byte i = 0; i < enabledPins; i++)
    {
        analogWrite(pwmPins[i], currentValue);
    }
}

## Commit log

2023-06-29 Build settings mode, serial output and led state
2023-06-29 Store LED state
2023-07-07 VoltmeterManager now handles all 3 voltmeters
2023-07-07 Changing and saving led level now separated
2023-07-07 LedManager now manages blink
2023-07-09 Voltmeter update now works correctly
2023-07-09 voltmeter changes
2023-07-09 Reworked SpeedLimitedController to PWMController
    [LedManager.cpp, PWMController.cpp, main.cpp]
2023-07-09 Replaced Voltmeters by PWMControllers
    [LedManager.cpp, PWMController.cpp, VoltmeterManager.cpp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]
2023-07-13 Fix bug in startup mode
    [VoltmeterManager.cpp, main.cpp]
2023-07-15 Change increments in calibration mode
2023-07-15 Correctly increment steps in calibration mode
    [main.cpp]
2023-07-19 Change button assignments
2023-07-22 Uniform step size for PWM
2023-07-26 Add additional assets used
    [Bottom Panel.3mf, Case.3mf, Dial Scale.dxf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]
2023-07-28 Improve accuracy of hour indicator by hardcoding pwm values
2024-01-28 Support rotary encoder inputs
2024-01-28 Use rotary encoder for led brightness
2024-03-23 Don't update LED on setup
2024-04-01 Remove gcode files and add new model for version 2
    [Bottom 2.0.3mf, Case 2.0.3mf, Encoder and Switch Fitting Test v1.3mf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]
2024-04-13 Version 2 assets
    [Front 2.0 v13.3mf, Kob v9.3mf]
2024-04-13 Increment in 2h steps during calibration mode
2024-04-16 Use 1h steps in calibration mode
2024-04-16 Remove pulsing mode from calibration and alarm set
2024-04-16 Calibrate hours
2024-04-16 Use interrupts for hours encoder and read encoders in a better way
2024-04-16 Update front asset
    [Front 2.0.3mf]
2024-04-19 Fix alarm fired state being kept if alarm is not enabled
    [main.cpp]
2024-04-19 Add serial printing when button 2 is pressed
